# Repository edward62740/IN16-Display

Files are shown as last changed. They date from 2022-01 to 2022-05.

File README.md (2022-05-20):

# WMNS IN-16

This is an Internet connected nixie tube display (4 x IN-16s) for displaying information (e.g CO2 levels, air quality...). It is designed to be used with [Wireless Mesh Network System](https://github.com/edward62740/Wireless-Mesh-Network-System) or other similar system with a database (InfluxDB, Firebase) to fetch and display information.

This project allows for seamless integration into existing smart home networks for displaying data which users may not want to access using an app/web application (i.e CO2 levels at a glance).

The provided software displays CO2 data on the device, and hosts a webserver to allow for adjustment of input source if necessary (i.e sensor 1/2).

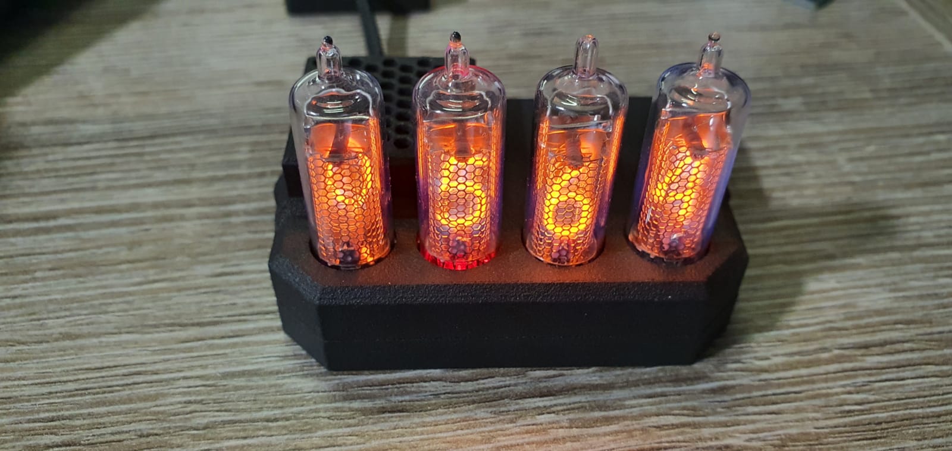
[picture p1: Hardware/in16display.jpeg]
IN-16 Display


The hardware consists of an ESP32 with GPIO expander, HV power supply, darlington arrays, fan and 4x in-16 tubes. It is based on the hardware from one of my other projects: [Project Nixie](https://github.com/devKarthikRaj/project-nixie "Project Nixie").

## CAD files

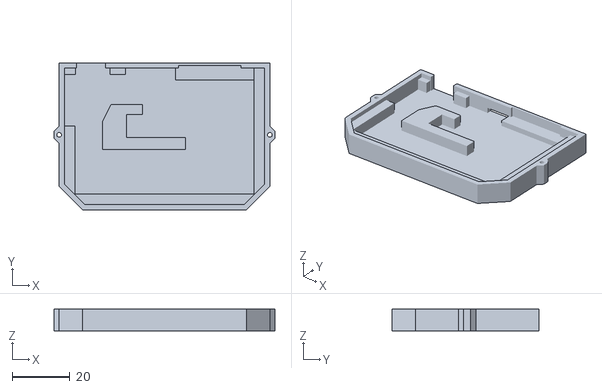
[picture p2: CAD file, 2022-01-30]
Hardware/in16 bottom.stl
76.5 x 50.9 x 7.60

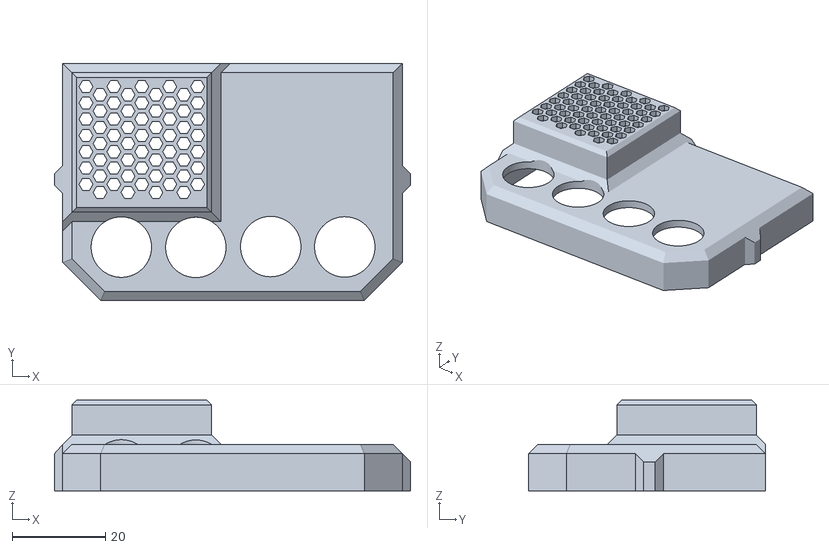
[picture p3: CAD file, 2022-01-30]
Hardware/in16 top.stl
76.5 x 51.0 x 19.5

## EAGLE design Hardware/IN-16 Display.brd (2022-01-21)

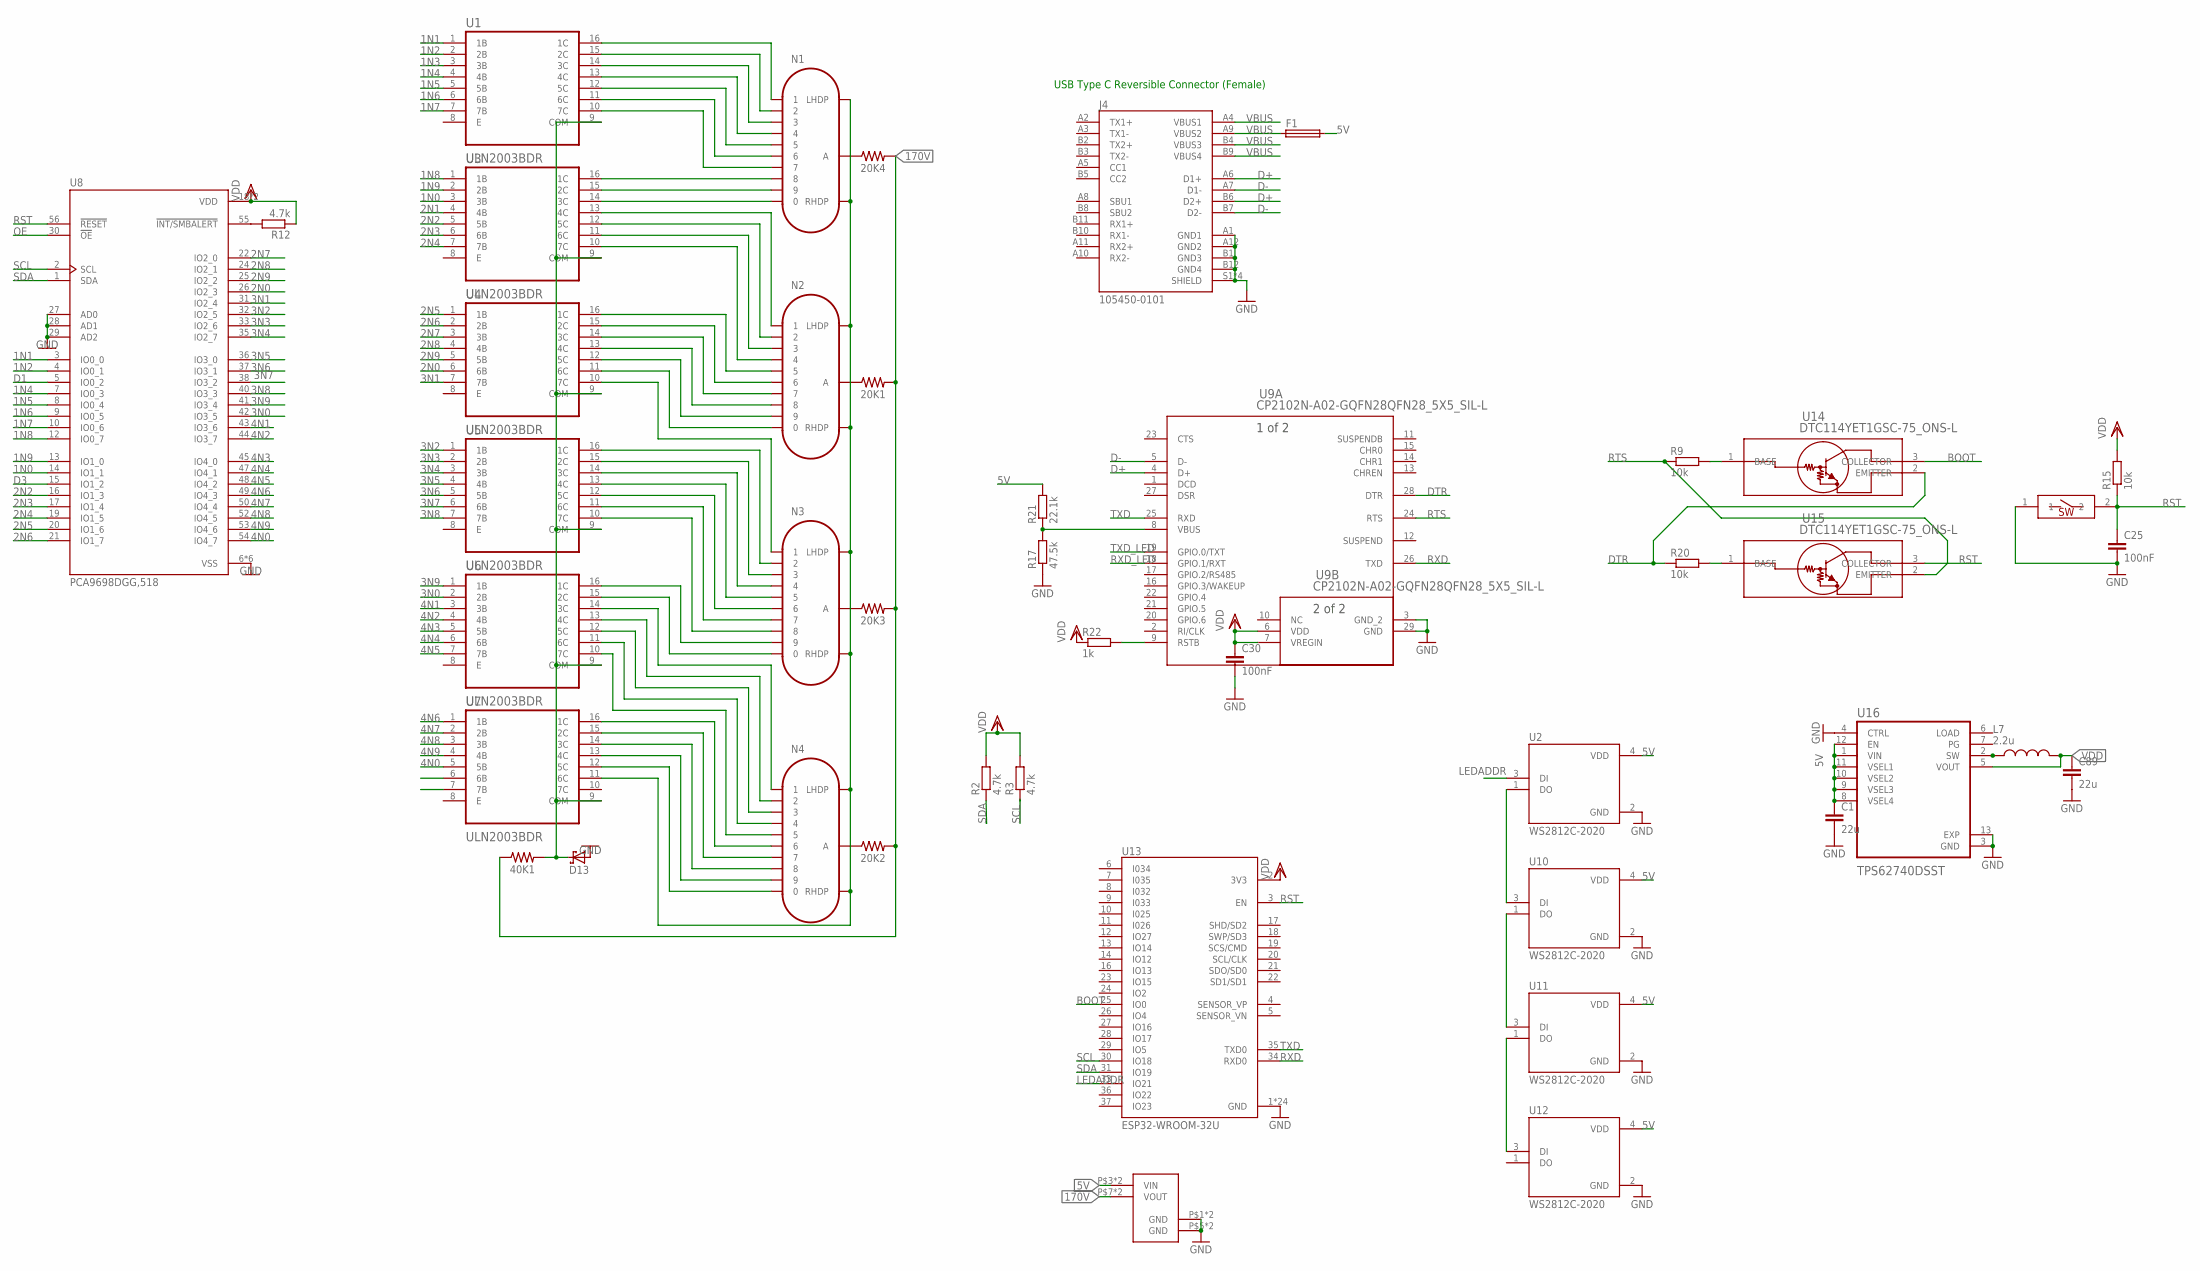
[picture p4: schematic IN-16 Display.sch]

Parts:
20K1, 20K2, 20K3, 20K4, 40K1: 0.05; 1210
C1, C89: 22u; C0603R
C25, C30: 100nF; C0402
D13: SCHOTTKY-DIODE; DIODE_SMB
F1: MF-MSMF050-2; 1812
J4: 105450-0101; MOLEX_105450-0101
L7: 2.2u; INDC3225X120N
N1, N2, N3, N4: IN-16
R2, R3, R12: 4.7k; R0402
R9, R15, R20: 10k; R0402
R17: 47.5k; R0402
R21: 22.1k; R0402
R22: 1k; R0402
RESET: SMDSWITCH; RESC4217X170
U1, U3, U4, U5, U6, U7: ULN2003BDR; SOIC127P600X175-16N
U2, U10, U11, U12: WS2812C-2020; LED_WS2812C-2020
U8: PCA9698DGG,518; SOP50P810X120-56N
U9: CP2102N-A02-GQFN28QFN28_5X5_SIL-L; QFN28_5X5_SIL-L
U13: ESP32-WROOM-32U; XCVR_ESP32-WROOM-32U
U14, U15: DTC114YET1GSC-75_ONS-L; SC-75_ONS-L
U16: TPS62740DSST; VREG_LM27762DSSR
U$1: HVPSU

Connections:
1N0: U3.3 (3B), U8.14 (IO1_1)
1N1: U1.1 (1B), U8.3 (IO0_0)
1N2: U1.2 (2B), U8.4 (IO0_1)
1N3: U1.3 (3B)
1N4: U1.4 (4B), U8.7 (IO0_3)
1N5: U1.5 (5B), U8.8 (IO0_4)
1N6: U1.6 (6B), U8.9 (IO0_5)
1N7: U1.7 (7B), U8.10 (IO0_6)
1N8: U3.1 (1B), U8.12 (IO0_7)
1N9: U3.2 (2B), U8.13 (IO1_0)
2N0: U4.6 (6B), U8.26 (IO2_3)
2N1: U3.4 (4B)
2N2: U3.5 (5B), U8.16 (IO1_3)
2N3: U3.6 (6B), U8.17 (IO1_4)
2N4: U3.7 (7B), U8.19 (IO1_5)
2N5: U4.1 (1B), U8.20 (IO1_6)
2N6: U4.2 (2B), U8.21 (IO1_7)
2N7: U4.3 (3B), U8.22 (IO2_0)
2N8: U4.4 (4B), U8.24 (IO2_1)
2N9: U4.5 (5B), U8.25 (IO2_2)
3N0: U6.2 (2B), U8.42 (IO3_5)
3N1: U4.7 (7B), U8.31 (IO2_4)
3N2: U5.1 (1B), U8.32 (IO2_5)
3N3: U5.2 (2B), U8.33 (IO2_6)
3N4: U5.3 (3B), U8.35 (IO2_7)
3N5: U5.4 (4B), U8.36 (IO3_0)
3N6: U5.5 (5B), U8.37 (IO3_1)
3N7: U5.6 (6B), U8.38 (IO3_2)
3N8: U5.7 (7B), U8.40 (IO3_3)
3N9: U6.1 (1B), U8.41 (IO3_4)
4N0: U7.5 (5B), U8.54 (IO4_7)
4N1: U6.3 (3B), U8.43 (IO3_6)
4N2: U6.4 (4B), U8.44 (IO3_7)
4N3: U6.5 (5B), U8.45 (IO4_0)
4N4: U6.6 (6B), U8.47 (IO4_1)
4N5: U6.7 (7B), U8.48 (IO4_2)
4N6: U7.1 (1B), U8.49 (IO4_3)
4N7: U7.2 (2B), U8.50 (IO4_4)
4N8: U7.3 (3B), U8.52 (IO4_5)
4N9: U7.4 (4B), U8.53 (IO4_6)
5V: C1.1, F1.2, R21.2, U2.4 (VDD), U10.4 (VDD), U11.4 (VDD), U12.4 (VDD), U16.1 (VIN), U16.8 (VSEL4), U16.9 (VSEL3), U16.10 (VSEL2), U16.11 (VSEL1), U16.12 (EN), U$1.P$3 (VIN), U$1.P$4 (VIN)
170V: 20K1.2, 20K2.2, 20K3.2, 20K4.2, 40K1.1, U$1.P$7 (VOUT), U$1.P$8 (VOUT)
BOOT: U13.25 (IO0), U14.3 (COLLECTOR)
D1: U8.5 (IO0_2)
D3: U8.15 (IO1_2)
D+: J4.A6 (D1+), J4.B6 (D2+), U9.4 (D+)
D-: J4.A7 (D1-), J4.B7 (D2-), U9.5 (D-)
DTR: R20.1, U9.28 (DTR), U14.2 (EMITTER)
GND: C1.2, C25.2, C30.2, C89.2, D13.A (C), J4.A1 (GND1), J4.A12 (GND2), J4.B1 (GND3), J4.B12 (GND4), J4.S1 (SHIELD), J4.S2 (SHIELD), J4.S3 (SHIELD), J4.S4 (SHIELD), R17.1, RESET.1, U2.2 (GND), U8.6 (VSS), U8.11 (VSS), U8.23 (VSS), U8.27 (AD0), U8.28 (AD1), U8.29 (AD2), U8.34 (VSS), U8.39 (VSS), U8.51 (VSS), U9.3 (GND_2), U9.29 (GND), U10.2 (GND), U11.2 (GND), U12.2 (GND), U13.1 (GND), U13.15 (GND), U13.38 (GND), U13.G.1 (GND), U13.G.2 (GND), U13.G.4 (GND), U13.G.5 (GND), U13.G.6 (GND), U13.G.7 (GND), U13.G.8 (GND), U13.G.9 (GND), U13.G.10 (GND), U13.G.11 (GND), U13.G.12 (GND), U13.G.13 (GND), U13.G.14 (GND), U13.G.15 (GND), U13.G.16 (GND), U13.G.17 (GND), U13.G.18 (GND), U13.G.19 (GND), U13.G.20 (GND), U13.G.21 (GND), U13.G.22 (GND), U16.3 (GND), U16.4 (CTRL), U16.13 (EXP), U$1.P$1 (GND), U$1.P$2 (GND), U$1.P$5 (GND), U$1.P$6 (GND)
LEDADDR: U2.3 (DI), U13.33 (IO21)
unnamed: N1.1, U1.16 (1C)
unnamed: N1.2, U1.15 (2C)
unnamed: N1.3, U1.14 (3C)
unnamed: N1.4, U1.13 (4C)
unnamed: N1.5, U1.12 (5C)
unnamed: N1.6, U1.11 (6C)
unnamed: N1.7, U1.10 (7C)
unnamed: N1.8, U3.16 (1C)
unnamed: N1.9, U3.15 (2C)
unnamed: N1.0, U3.14 (3C)
unnamed: N2.1, U3.13 (4C)
unnamed: N2.2, U3.12 (5C)
unnamed: N2.3, U3.11 (6C)
unnamed: N2.4, U3.10 (7C)
unnamed: N2.5, U4.16 (1C)
unnamed: N2.6, U4.15 (2C)
unnamed: N2.7, U4.14 (3C)
unnamed: N2.8, U4.13 (4C)
unnamed: 20K4.1, N1.A
unnamed: N2.9, U4.12 (5C)
unnamed: N2.0, U4.11 (6C)
unnamed: N3.1, U4.10 (7C)
unnamed: N3.2, U5.16 (1C)
unnamed: N3.3, U5.15 (2C)
unnamed: N3.4, U5.14 (3C)
unnamed: N3.5, U5.13 (4C)
unnamed: N3.6, U5.12 (5C)
unnamed: N3.7, U5.11 (6C)
unnamed: N3.8, U5.10 (7C)
unnamed: N3.9, U6.16 (1C)
unnamed: N3.0, U6.15 (2C)
unnamed: N4.1, U6.14 (3C)
unnamed: N4.2, U6.13 (4C)
unnamed: N4.3, U6.12 (5C)
unnamed: N4.4, U6.11 (6C)
unnamed: N4.5, U6.10 (7C)
unnamed: R20.2, U15.1 (BASE)
unnamed: N4.6, U7.16 (1C)
unnamed: N4.7, U7.15 (2C)
unnamed: N4.8, U7.14 (3C)
unnamed: N4.9, U7.13 (4C)
unnamed: N4.0, U7.12 (5C)
unnamed: 20K1.1, N2.A
unnamed: 20K2.1, N4.A
unnamed: 20K3.1, N3.A
unnamed: R17.2, R21.1, U9.8 (VBUS)
unnamed: R22.2, U9.9 (RSTB)
unnamed: R9.2, U14.1 (BASE)
unnamed: U2.1 (DO), U10.3 (DI)
unnamed: U10.1 (DO), U11.3 (DI)
unnamed: U11.1 (DO), U12.3 (DI)
unnamed: N1.LHDP, N1.RHDP, N2.LHDP, N2.RHDP, N3.LHDP, N3.RHDP, N4.LHDP, N4.RHDP, U7.11 (6C)
unnamed: 40K1.2, D13.C (A), U1.9 (COM), U3.9 (COM), U4.9 (COM), U5.9 (COM), U6.9 (COM), U7.9 (COM)
unnamed: L7.1, U16.2 (SW)
unnamed: R12.2, U8.55 (!INT/SMBALERT)
OE: U8.30 (!OE)
RST: C25.1, R15.1, RESET.2, U8.56 (!RESET), U13.3 (EN), U15.3 (COLLECTOR)
RTS: R9.1, U9.24 (RTS), U15.2 (EMITTER)
RXD: U9.26 (TXD), U13.34 (RXD0)
RXD_LED: U9.18 (GPIO.1/RXT)
SCL: R3.1, U8.2 (SCL), U13.30 (IO18)
SDA: R2.1, U8.1 (SDA), U13.31 (IO19)
TXD: U9.25 (RXD), U13.35 (TXD0)
TXD_LED: U9.19 (GPIO.0/TXT)
VBUS: F1.1, J4.A4 (VBUS1), J4.A9 (VBUS2), J4.B4 (VBUS3), J4.B9 (VBUS4)
VDD: C30.1, C89.1, L7.2, R2.2, R3.2, R12.1, R15.2, R22.1, U8.18 (VDD), U8.46 (VDD), U9.6 (VDD), U9.7 (VREGIN), U13.2 (3V3), U16.5 (VOUT)

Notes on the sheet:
USB Type C Reversible Connector (Female)

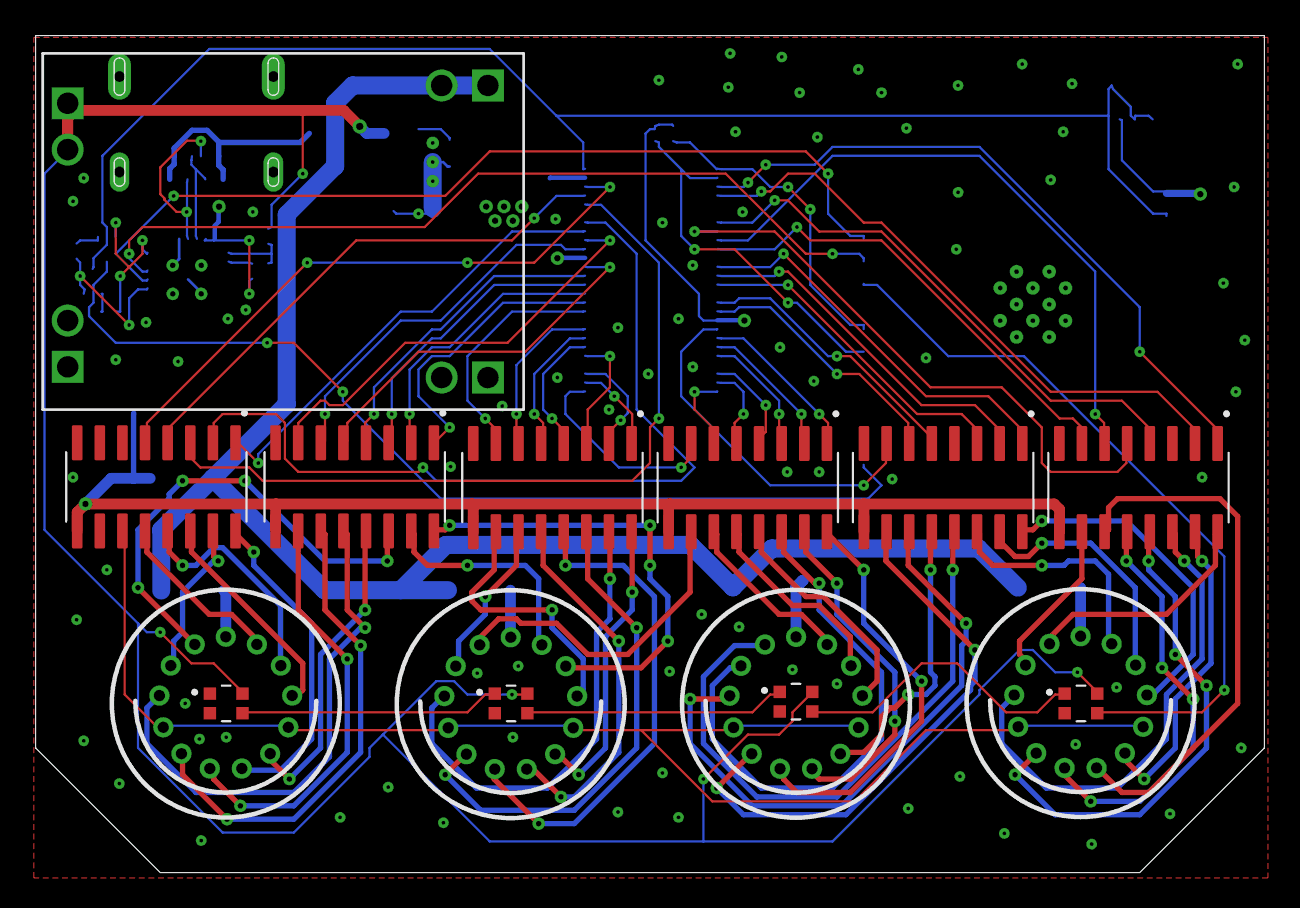
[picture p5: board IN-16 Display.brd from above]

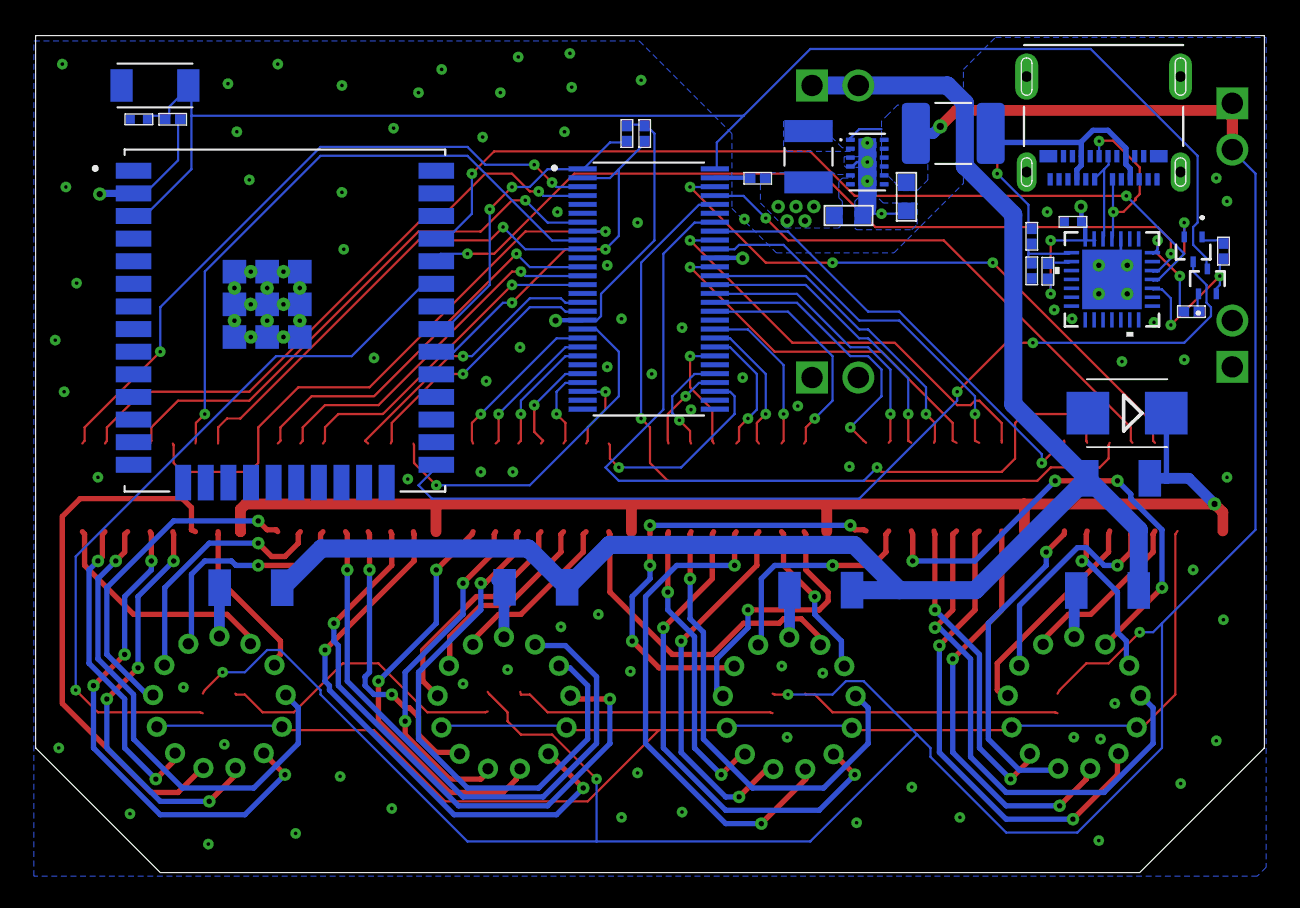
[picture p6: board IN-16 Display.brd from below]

Board: 4 copper layers, 69.0 x 47.0 mm, 44 parts (29 on the bottom side), 109 nets.

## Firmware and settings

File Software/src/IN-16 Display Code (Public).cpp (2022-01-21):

#include "Arduino.h"
#include <Wire.h>
#include "NTC_PCA9698.h"
#include <WiFi.h>
#include <NTPClient.h>
#include <AsyncTCP.h>
#include <ESPAsyncWebServer.h>
#define DEVICE "ESP32"
#include <InfluxDbClient.h>
#include <InfluxDbCloud.h>
#include <esp_wifi.h>
#include "num2disp.h"
#include <EEPROM.h>
#include <WS2812FX.h>

String processor(const String &var);
String outputState(int output);
void tubes(void *pvParameters);
void leds(void *pvParameters);
bool num2disp_gpio_write(uint8_t pin, bool data);

/* InfluxDB Connection Parameters */
#define WIFI_SSID "."
#define WIFI_PASSWORD "."
#define INFLUXDB_URL "."
#define INFLUXDB_TOKEN "."
#define INFLUXDB_ORG "."
#define INFLUXDB_BUCKET "."
#define TZ_INFO "."

// define the number of bytes you want to access
#define EEPROM_SIZE 1
String hostname = "IN-16 DISPLAY";
int intblk = 0;
#ifdef __cplusplus
extern "C"
{
#endif

  uint8_t temprature_sens_read();

#ifdef __cplusplus
}
#endif

TimerHandle_t cathodeProtectionTimer;
TimerHandle_t ifdbTimer;
bool run_protection = false;
bool post = false;
bool changed = false;
bool state = false;

String query = "from(bucket: \"MESH\") |> range(start: -10m) |> filter(fn: (r) => r._measurement == \"CO2\") |> filter(fn: (r) => r.UID == \"xxxx\") |> filter(fn: (r) => r._field == \"CO2\") |> last()";
/* Task handles */
static TaskHandle_t serp;
static TaskHandle_t disp;


uint32_t value = 0;
uint32_t prev_value = 123400;
unsigned long previousMillis = 0;
#define DISPLAY_UPDATE_RATE_MS 5000
#define CATHODE_PROTECTION_INTERVAL_MS 600000
#define CATHODE_PROTECTION_RUNTIME_MS 10000
WS2812FX ws2812fx = WS2812FX(4, 21, NEO_GRB + NEO_KHZ800); //(LED_COUNT,LED_PIN,NEO_GRB + NEO_KHZ800)
NumericalDisplay_t tube1;
uint8_t pinout1[10] = {39, 30, 31, 32, 33, 34, 35, 36, 37, 38};
NumericalDisplay_t tube2;
uint8_t pinout2[10] = {29, 20, 21, 22, 23, 24, 25, 26, 27, 28};
NumericalDisplay_t tube3;
uint8_t pinout3[10] = {19, 10, 11, 12, 13, 14, 15, 16, 17, 18};
NumericalDisplay_t tube4;
uint8_t pinout4[10] = {9, 0, 1, 2, 3, 4, 5, 6, 7, 8};
NumericalDisplay_t tube5;
NumericalDisplay_t tube6;

const char *PARAM_INPUT_1 = "output";
const char *PARAM_INPUT_2 = "state";

/* InfluxDB Data Points */
Point Display("IN-16 Display");

PCA9698 gp0(0x20, 19, 18, 100000); // instantiate PCA9698(I2C address, SDA, SCL, I2C speed)
InfluxDBClient client(INFLUXDB_URL, INFLUXDB_ORG, INFLUXDB_BUCKET, INFLUXDB_TOKEN, InfluxDbCloud2CACert);
AsyncWebServer server(80);

const char index_html[] PROGMEM = R"rawliteral(
<!DOCTYPE HTML><html>
<head>
  <title>CO2 Display Output</title>
  
  <meta name="viewport" content="width=device-width, initial-scale=1">
  <link rel="icon" href="data:,">
  <style>
    html {font-family: Arial; display: inline-block; text-align: center;}
    h2 {font-size: 3.0rem;}
    p {font-size: 3.0rem;}
    body {max-width: 600px; margin:0px auto; padding-bottom: 25px;}
    .switch {position: relative; display: inline-block; width: 120px; height: 68px} 
    .switch input {display: none}
    .slider {position: absolute; top: 0; left: 0; right: 0; bottom: 0; background-color: #ccc; border-radius: 6px}
    .slider:before {position: absolute; content: ""; height: 52px; width: 52px; left: 8px; bottom: 8px; background-color: #2700ff; -webkit-transition: .4s; transition: .4s; border-radius: 3px}
    input:checked+.slider {background-color: #b30000}
    input:checked+.slider:before {-webkit-transform: translateX(52px); -ms-transform: translateX(52px); transform: translateX(52px)}
  </style>
</head>
<body>

  <h2>CO2 Display Output</h2>
     <h4>CO2 (ppm):  <span id="co2">%CO2%</span></h4>
     <h4>CPU Temperature:  <span id="cputemp">%temp%</span></h4>

  %BUTTONPLACEHOLDER%
  
<script>
setInterval(updateValues, 1000, "co2");
setInterval(updateValues, 1000, "cputemp");

function toggleCheckbox(element) {
  var xhr = new XMLHttpRequest();
  if(element.checked){ xhr.open("GET", "/update?output="+element.id+"&state=1", true); }
  else { xhr.open("GET", "/update?output="+element.id+"&state=0", true); }
  xhr.send();
}
function updateValues(value) {
  var xhttp = new XMLHttpRequest();
  xhttp.onreadystatechange = function() {
    if (this.readyState == 4 && this.status == 200) {
      document.getElementById(value).innerHTML = this.responseText;
    }
  };
  xhttp.open("GET", "/" + value, true);
  xhttp.send();
}
</script>
</body>
</html>
)rawliteral";

// Replaces placeholder with button section in your web page
String processor(const String &var)
{
  //Serial.println(var);
  if (var == "BUTTONPLACEHOLDER")
  {
    String buttons = "";
    buttons += "<h4> Sensor 1   <---->   Sensor 2 </h4><label class=\"switch\"><input type=\"checkbox\" onchange=\"toggleCheckbox(this)\" id=\"2\" " + outputState(2) + "><span class=\"slider\"></span></label>";
    return buttons;
  }
  return String();
}

String outputState(int output)
{
  if (state)
  {
    return "checked";
  }
  else
  {
    return "";
  }
}

void vTimerCallback1(TimerHandle_t cathodeProtectionTimer)
{
  run_protection = true;
}

void vTimerCallback2(TimerHandle_t ifdbTimer)
{
  post = true;
}
void setup()
{

  Serial.begin(115200);
  EEPROM.begin(EEPROM_SIZE);
  // put your setup code here, to run once:
  if (EEPROM.read(0) == 0)
  {
    state = false;
    query = "from(bucket: \"xxxx\") |> range(start: -30m) |> filter(fn: (r) => r._measurement == \"xxxx\") |> filter(fn: (r) => r.UID == \"xxxx\") |> filter(fn: (r) => r._field == \"xxxx\") |> last()";
  }
  else
  {
    state = true;
    query = "from(bucket: \"xxxx\") |> range(start: -30m) |> filter(fn: (r) => r._measurement == \"xxxx\") |> filter(fn: (r) => r.UID == \"xxxx\") |> filter(fn: (r) => r._field == \"xxxx\") |> last()";
  }
  num2disp_createInstanceNumericalDisplay(&tube1, pinout1);
  num2disp_createInstanceNumericalDisplay(&tube2, pinout2);
  num2disp_createInstanceNumericalDisplay(&tube3, pinout3);
  num2disp_createInstanceNumericalDisplay(&tube4, pinout4);
  num2disp_createInstanceFullDisplay(&tube1, &tube2, &tube3, &tube4, &tube5, &tube6, 4, 0);
  delay(100);
  Serial.println("[INIT] STARTUP INITIALIZATION OK");

  WiFi.begin(WIFI_SSID, WIFI_PASSWORD);
  WiFi.mode(WIFI_STA);
  WiFi.config(INADDR_NONE, INADDR_NONE, INADDR_NONE, INADDR_NONE);
  WiFi.setHostname(hostname.c_str()); //define hostname
  while (WiFi.status() != WL_CONNECTED)
  {
    Serial.println("[INIT] ERROR CONNECTING TO WIFI");
    WiFi.disconnect();
    WiFi.begin(WIFI_SSID, WIFI_PASSWORD);
    vTaskDelay(2000);
  }
  Serial.println("[INIT] WIFI CONNECTION OK");

  timeSync(TZ_INFO, "pool.ntp.org", "time.nis.gov");

  //client.setHTTPOptions(HTTPOptions().httpReadTimeout(200));
  client.setHTTPOptions(HTTPOptions().connectionReuse(true));
  // Check server connection
  if (client.validateConnection())
  {
    Serial.print("Connected to InfluxDB: ");
    Serial.println(client.getServerUrl());
  }
  else
  {
    Serial.print("InfluxDB connection failed: ");
    Serial.println(client.getLastErrorMessage());
  }
  Serial.println("[INIT] IFDB CONNECTION OK");
  ifdbTimer = xTimerCreate("Timer2", 120000, pdTRUE, (void *)0, vTimerCallback2);
  xTimerStart(ifdbTimer, 0);
  xTaskCreatePinnedToCore(
      tubes,   //Task Function
      "tubes", //Name of Task
      10000,   //Stack size of task
      NULL,    //Parameter of the task
      1,       //Priority of the task
      NULL,    //Task handle to keep track of the created task
      0);      //Target Core

  xTaskCreatePinnedToCore(
      leds,   //Task Function
      "leds", //Name of Task
      10000,  //Stack size of task
      NULL,   //Parameter of the task
      1,      //Priority of the task
      NULL,   //Task handle to keep track of the created task
      1);     //Target Core

  //Core 1 Config

  // Route for root / web page
  server.on("/", HTTP_GET, [](AsyncWebServerRequest *request)
            { request->send_P(200, "text/html", index_html, processor); });

  // Send a GET request to <ESP_IP>/update?output=<inputMessage1>&state=<inputMessage2>
  server.on("/update", HTTP_GET, [](AsyncWebServerRequest *request)
            {
              String inputMessage1;
              String inputMessage2;
              // GET input1 value on <ESP_IP>/update?output=<inputMessage1>&state=<inputMessage2>
              if (request->hasParam(PARAM_INPUT_1) && request->hasParam(PARAM_INPUT_2))
              {
                inputMessage1 = request->getParam(PARAM_INPUT_1)->value();
                inputMessage2 = request->getParam(PARAM_INPUT_2)->value();
                digitalWrite(inputMessage1.toInt(), inputMessage2.toInt());
                if (inputMessage1.toInt() == 2 && inputMessage2.toInt() == 0)
                {
                  query = "from(bucket: \"xxxx\") |> range(start: -30m) |> filter(fn: (r) => r._measurement == \"xxxx\") |> filter(fn: (r) => r.UID == \"xxxx\") |> filter(fn: (r) => r._field == \"xxxx\") |> last()";
                  changed = true;
                  state = false;
                  EEPROM.write(0, state);
                  EEPROM.commit();
                  Serial.print(EEPROM.read(0));
                }
                else if (inputMessage1.toInt() == 2 && inputMessage2.toInt() == 1)
                {
                  query = "from(bucket: \"xxxx\") |> range(start: -30m) |> filter(fn: (r) => r._measurement == \"xxxx\") |> filter(fn: (r) => r.UID == \"xxxx\") |> filter(fn: (r) => r._field == \"xxxx\") |> last()";
                  changed = true;
                  state = true;
                  EEPROM.write(0, state);
                  EEPROM.commit();
                  Serial.print(EEPROM.read(0));
                }
              }
              else
              {
                inputMessage1 = "No message sent";
                inputMessage2 = "No message sent";
              }
              request->send(200, "text/plain", "OK");
            });

  // Start server
  server.begin();
  vTaskDelete(NULL);
}

void tubes(void *pvParameters)
{
  Wire.begin(19, 18, 100000);
  gp0.configuration();     // soft reset and configuration
  gp0.portMode(0, OUTPUT); // set port directions
  gp0.portMode(1, OUTPUT);
  gp0.portMode(2, OUTPUT);
  gp0.portMode(3, OUTPUT);
  gp0.portMode(4, OUTPUT);
  for (int i = 0; i < 40; i++)
  {
    gp0.digitalWrite(i, LOW);
  }
  uint32_t x = 123400;
  num2disp_writeNumberToFullDisplay(x, x - 1, true);
  while (1)
  {
    //  Serial.print(WiFi.RSSI());

    unsigned long currentMillis = millis();

    if ((currentMillis - previousMillis >= 5000) || changed)
    {
      // save the last time you blinked the LED
      previousMillis = currentMillis;
      FluxQueryResult result = client.query(query);
      while (result.next())
      {
        Serial.println(EEPROM.read(0));
        double blocker = result.getValueByName("_value").getDouble();
        value = (uint32_t)blocker * 100;
        intblk = (int)blocker;
        server.on("/co2", HTTP_GET, [intblk](AsyncWebServerRequest *request)
                  { request->send(200, "text/plain", String(intblk)); });
        server.on("/cputemp", HTTP_GET, [intblk](AsyncWebServerRequest *request)
                  { request->send(200, "text/plain", String((temprature_sens_read() - 32) / 1.8)); });
        Serial.println(String(intblk));
        num2disp_writeNumberToFullDisplay(value, prev_value, true);
        prev_value = value;
      }
      Serial.print(result.getError());
      changed = false;
      if (result.getError() != "")
      {
        changed = true;
        Serial.print("ERROR");
        client.validateConnection();
      }
    }
    if (post)
    {
      num2disp_runCathodePoisoningProtection(50, CATHODE_PROTECTION_STYLE_SLOT);
      post = false;
      num2disp_clearNumberFromFullDisplay();
      num2disp_writeNumberToFullDisplay(value, prev_value, true);
    }
  }
}

void leds(void *pvParameters)
{
  ws2812fx.init();
  ws2812fx.setBrightness(255);
  ws2812fx.setSpeed(255);
  ws2812fx.setMode(FX_MODE_RAINBOW_CYCLE);
  ws2812fx.start();
  while (1)
  {
    delay(1);
    ws2812fx.service();
  }
}
void loop()
{
}

bool num2disp_gpio_write(uint8_t pin, bool data)
{
  gp0.digitalWrite(pin, data);
  return false;
}

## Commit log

2022-01-21 Added preliminary
    [IN-16 Display.brd, IN-16 Display.sch]
2022-01-30 Added stl
    [in16 bottom.stl, in16 top.stl]

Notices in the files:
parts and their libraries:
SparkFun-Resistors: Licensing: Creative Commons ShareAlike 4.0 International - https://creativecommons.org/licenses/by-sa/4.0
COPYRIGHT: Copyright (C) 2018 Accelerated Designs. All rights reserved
